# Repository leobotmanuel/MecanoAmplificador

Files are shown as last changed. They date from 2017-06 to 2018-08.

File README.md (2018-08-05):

# Mecano Amplificador  

## Comunicación libre. Jornadas de Bajo Coste.
### Albacete, Julio 2017
Dispositivo programable del proyecto Amplificación Mecanoceptiva de Maite Aliaga.

Presentación de la [Comunicación Libre](https://github.com/leobotmanuel/MecanoAmplificador/blob/master/doc/ALIAGAamplificacionmecanoceptiva.pdf) en las [Jornadas de Bajo Coste](http://www.crmfalbacete.org/recursosbajocoste/default.asp) de Albacete, 6-7-8 de Julio de 2017.

Dispositivo Mecano Amplificador, [dossier concurso](https://github.com/leobotmanuel/MecanoAmplificador/blob/master/doc/ALIAGAdossierconcursoBajoCoste2017AmplificacionMecanoceptiva.pdf).

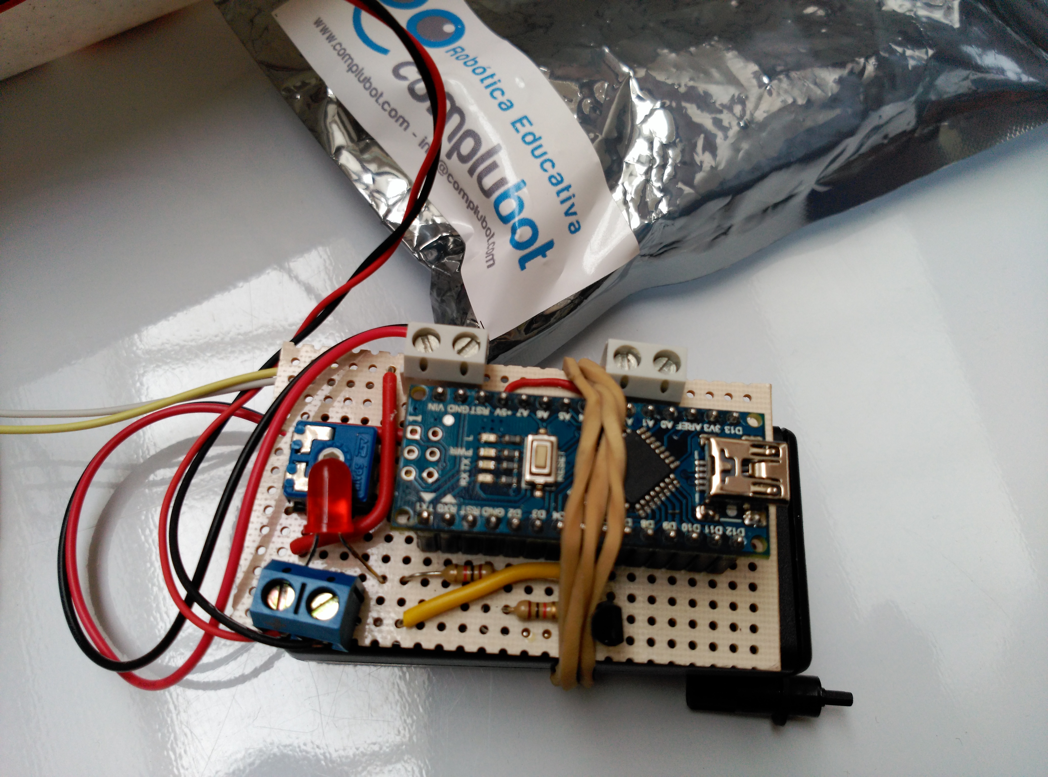
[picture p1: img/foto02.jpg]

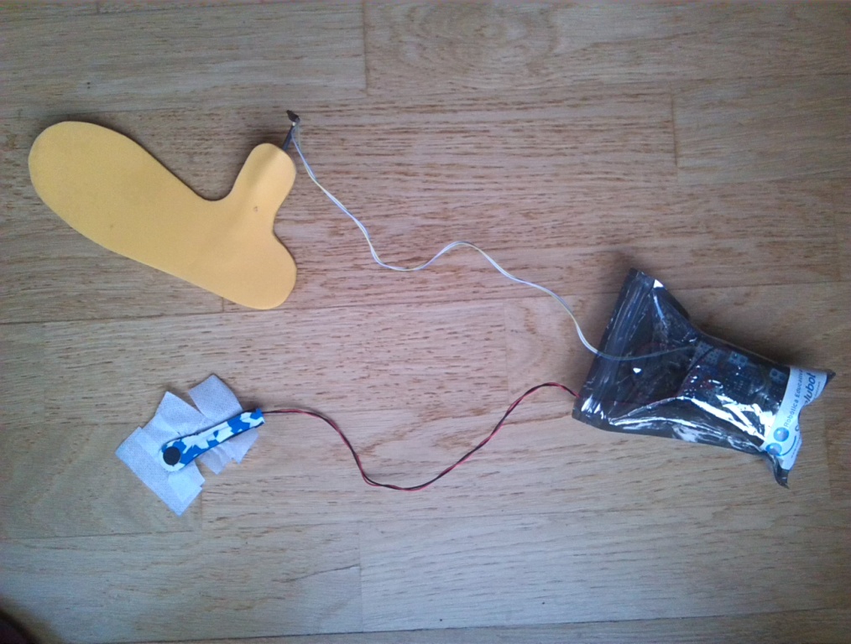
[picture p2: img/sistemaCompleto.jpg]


Colcación del Mecano Amplificador en las personas.

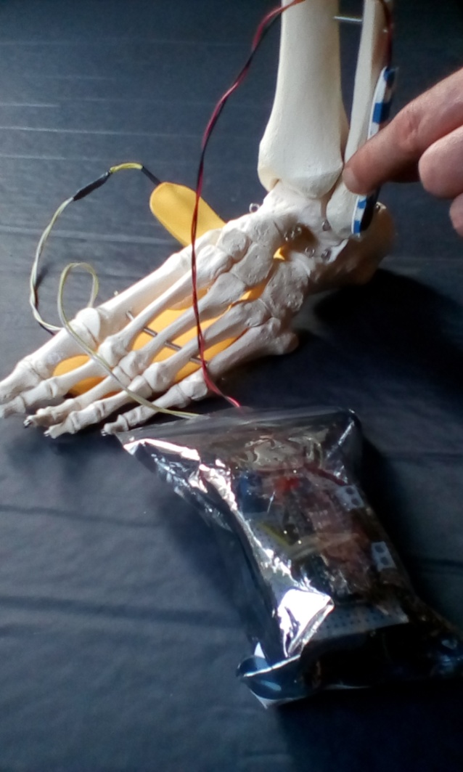
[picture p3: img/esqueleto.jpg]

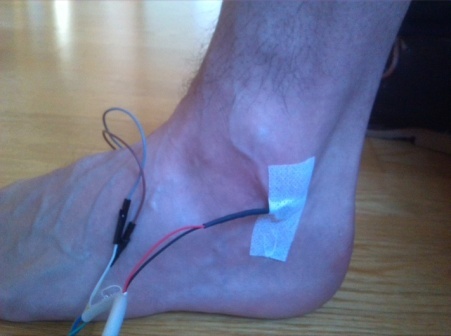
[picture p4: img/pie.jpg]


Programa para el [Nano-Arduino](https://github.com/leobotmanuel/MecanoAmplificador/blob/master/software/mecanoAmplificador.ino)

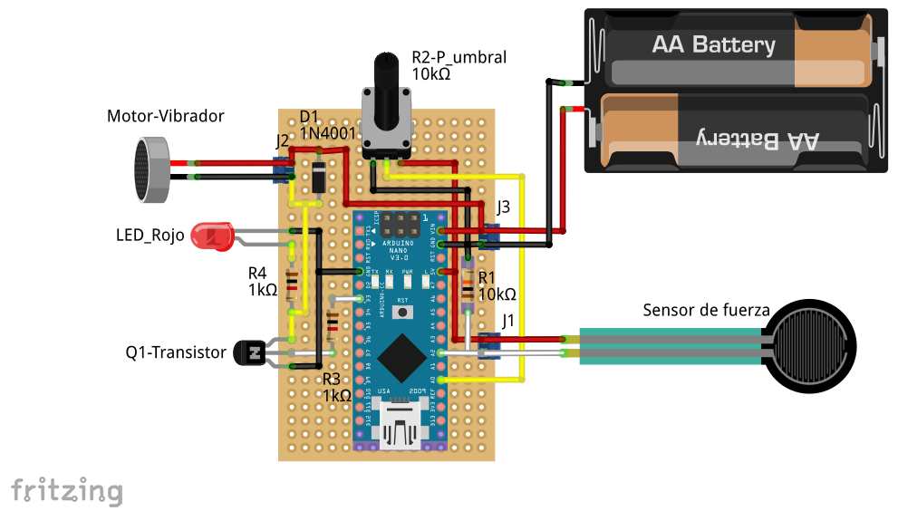
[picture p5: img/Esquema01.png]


[Esquema electrónico](https://github.com/leobotmanuel/MecanoAmplificador/blob/master/doc/Esquema02.fzz)

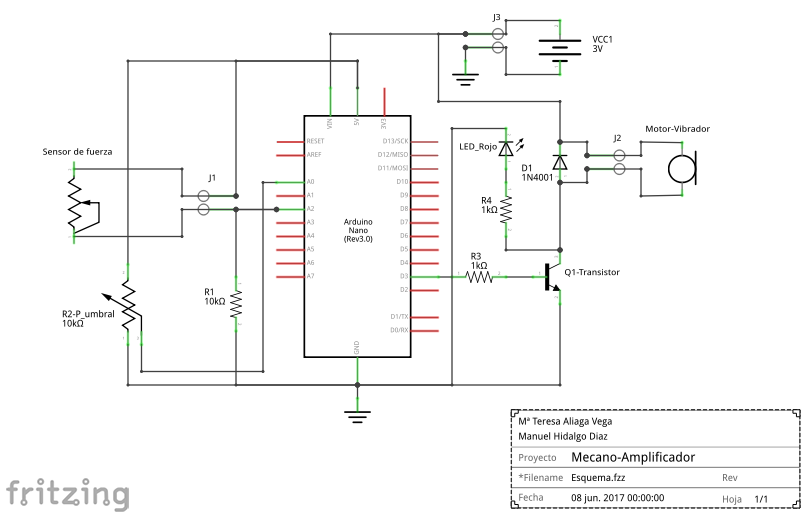
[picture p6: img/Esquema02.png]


[PROPUESTAS DE MEJORA](https://github.com/leobotmanuel/MecanoAmplificador/blob/master/doc/propuesta/README.md)

[Volver índice](https://mecanoceptiva.github.io/)

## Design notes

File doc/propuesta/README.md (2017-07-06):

# Propuestas de mejora


- Reducir el tamaño  del sistema completo.
- Conseguir una autonomia aceptable.
- Colocar de manera cómoda y funcional.

[ARDUINO MINI](https://store.arduino.cc/arduino-mini-05)

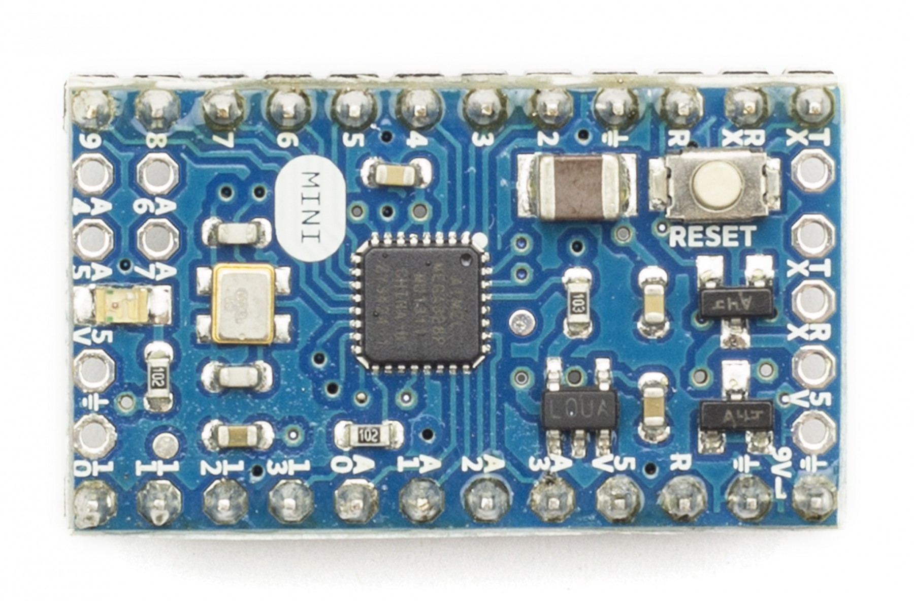
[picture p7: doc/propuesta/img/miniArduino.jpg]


[WEMOS](http://robotpersonal.es/product.php?id_product=223)

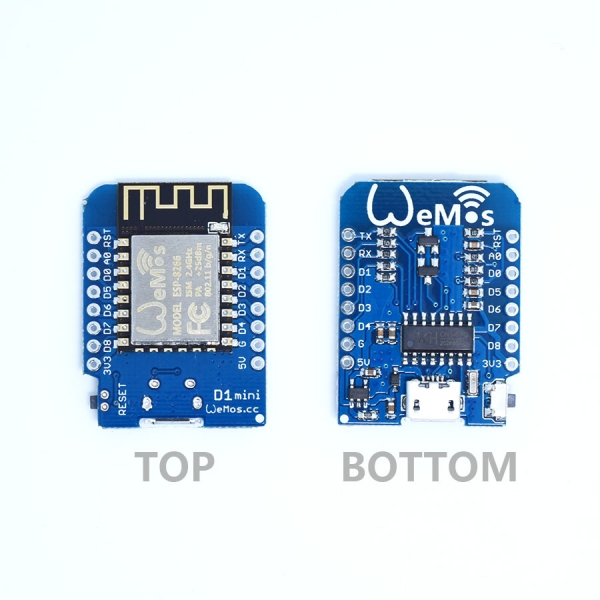
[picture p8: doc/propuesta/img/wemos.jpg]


[Shield](http://robotpersonal.es/category.php?id_category=89) para Wemos

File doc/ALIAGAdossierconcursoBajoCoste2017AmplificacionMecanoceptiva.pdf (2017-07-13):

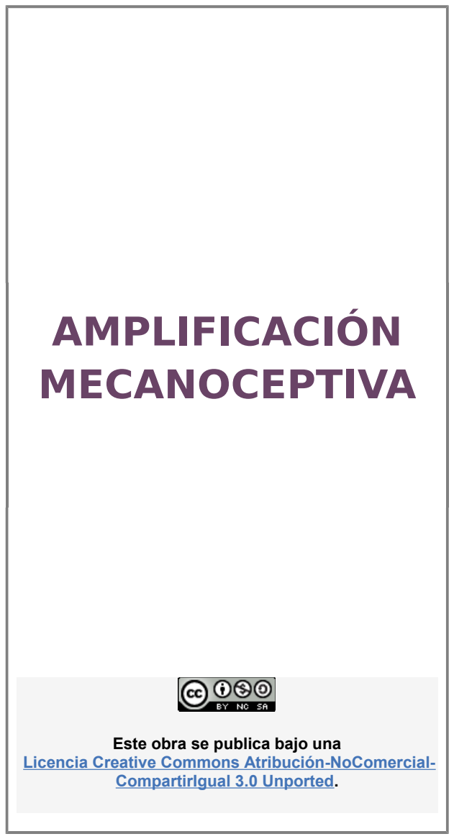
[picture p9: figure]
AMPLIFICACIÓN MECANOCEPTIVA; Este obra se publica bajo una Licencia Creative Commons Atribución-NoComercial- CompartirIgual 3.0 Unported.

# AMPLIFICACIÓN MECANOCEPTIVA

### Breve descripción

Presentamos un prototipo de dispositivo electrónico portátil para proporcionar mecano-estimulación funcional.

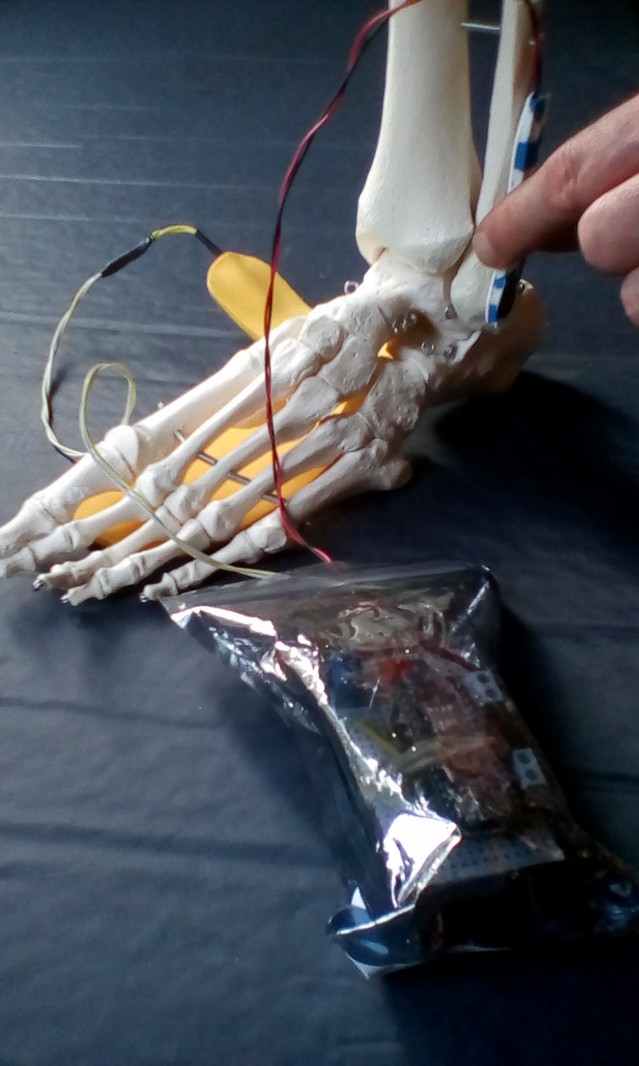
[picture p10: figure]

Este proyecto tecnológico busca potenciar el funcionamiento natural del aparato osteo-articular como órgano sensorial, para que tenga un rol preponderante en la organización de la musculatura durante las diferentes posturas o desplazamientos.

### Para quién se hizo y con qué objeto

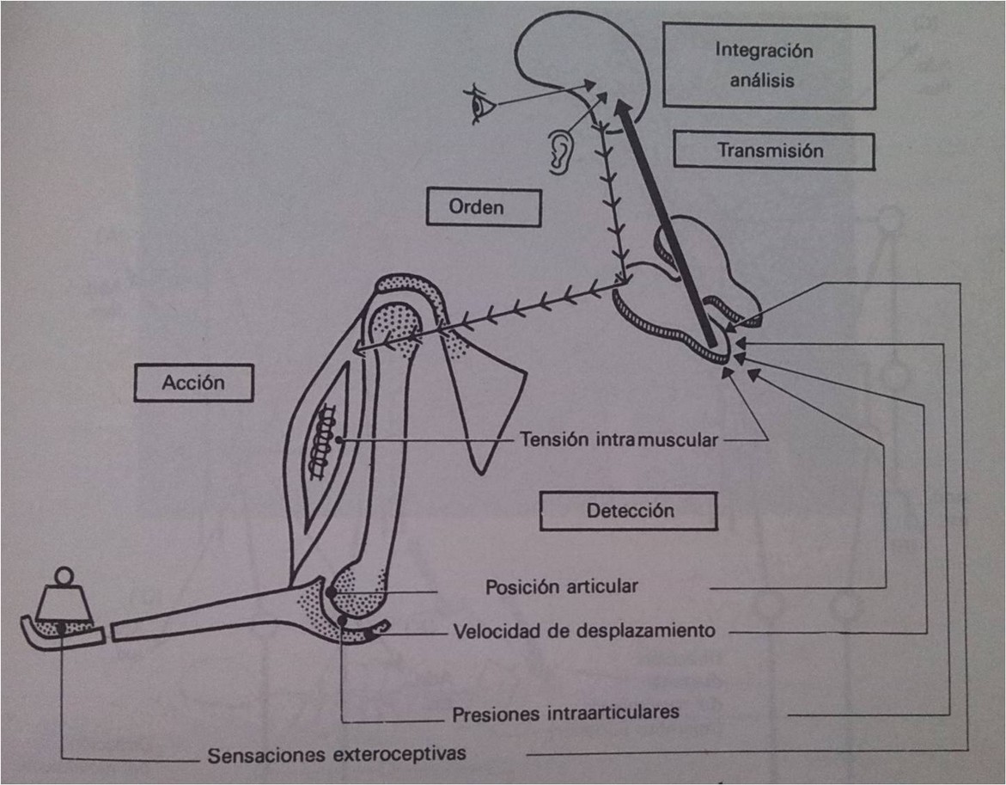
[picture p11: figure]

DISFUNCIONES EN LA PERCEPCIÓN DE LA PROPIA POSTURA CORPORAL Y DE LOS PROPIOS MOVIMIENTOS EN EL ESPACIO

La motricidad se coordina automáticamente desde el sistema nervioso central (encéfalo y médula espinal) gracias a la información procedente de diversos receptores sensoriales: visión, sistema vestibular, tacto y propiocepción (muscular y periarticular).

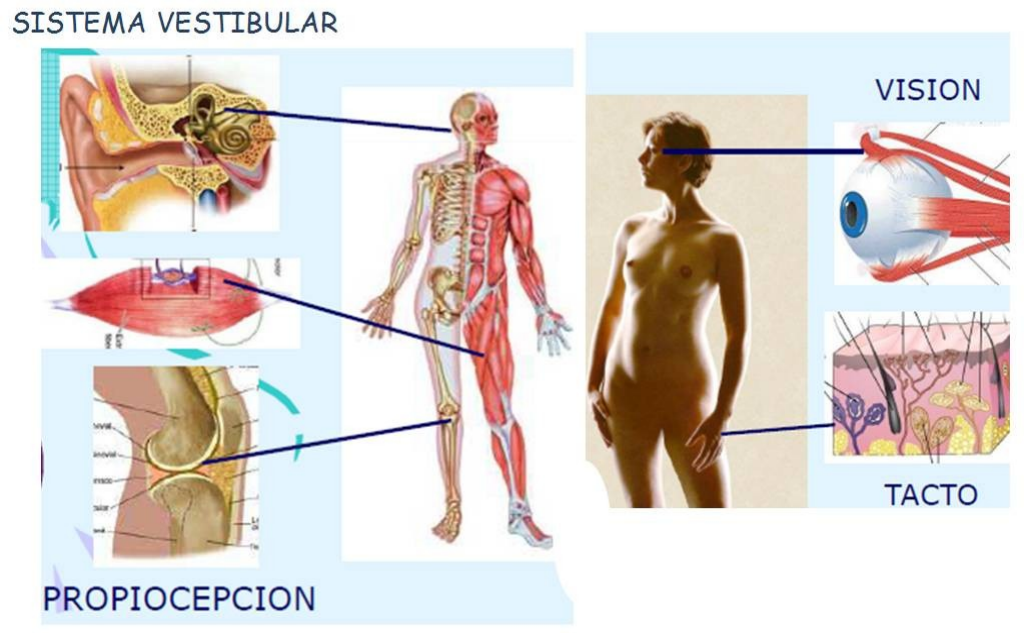
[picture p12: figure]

En caso de una patología que afecte al circuito neurológico de la contracción muscular habrá un
mal | funcionamiento | en | los | "husos
neuromusculares", unos muelles sensores de la longitud y de la velocidad con que se está tensando o relajando cada músculo.

Si su circuito sensorio-motor alternativo no está afectado por la lesión original, otros sensores llamados "mecanoceptores", existentes en los tejidos de alrededor de las articulaciones (tendones y fascias, ligamentos y cápsulas, superficies de contacto entre los huesos) seguirán informando adecuadamente sobre la posición y las presiones en el esqueleto.

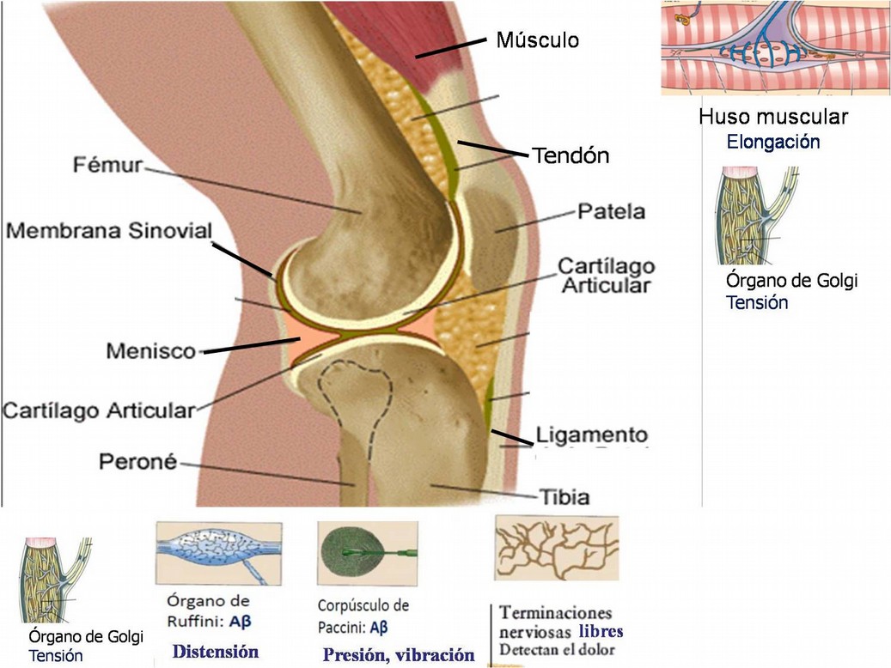
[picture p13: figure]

Vamos a traducir esto a nivel funcional. Por ejemplo durante la marcha, el tobillo y la rodilla deben flexionarse suavemente para amortiguar la pisada. Sin embargo en los niños o adultos con hemiplejia, el músculo tríceps sural de la extremidad inferior afectada suele presentar contracciones excesivas o a destiempo y fallos en el momento de necesitar relajarse ("hipertonia", “espasticidad”).

Esta descoordinación produce una extensión errónea del tobillo y de la rodilla que impide soportar el apoyo del cuerpo sobre el pie, perdiendo mucha estabilidad al dar pasos con la

otra extremidad inferior.

POSIBILIDADES TERAPÉUTICAS
De momento las intervenciones médicas (ortesis para ayudar a posicionar las articulaciones, fármacos paralizantes o cirugía debilitadora sobre los músculos…) solamente han podido contener parcialmente dichas consecuencias biomecánicas adversas de una mala regulación neuromotríz.

Existen por otra parte en Fisioterapia y Psicología técnicas o ejercicios que han demostrado empíricamente una armonización general aunque transitoria de las tensiones musculares, conseguida desde algún tipo de estimulación mecánica realizada sobre el esqueleto.

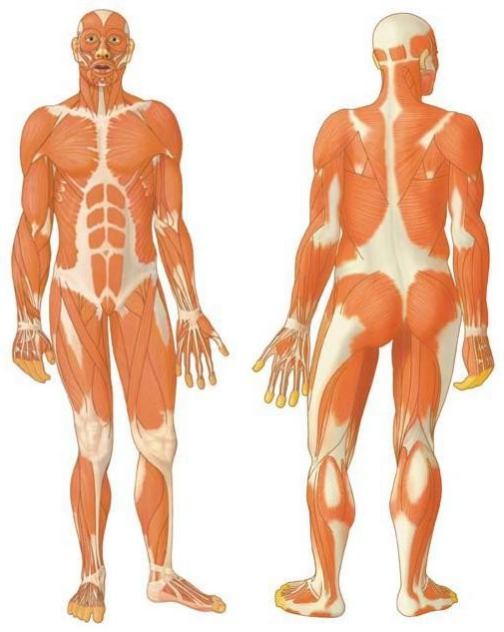
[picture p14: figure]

Observando en conjunto las prominencias óseas más favorables y las direcciones de presión más eficaces encontramos un patrón biomecánico simulando el enderezamiento postural automático contra la gravedad y los impactos recibidos por el cuerpo humano cuando está moviéndose sobre una
superficie | de | desplazamiento | (volteando,
sentándose, gateando, caminando, etc).

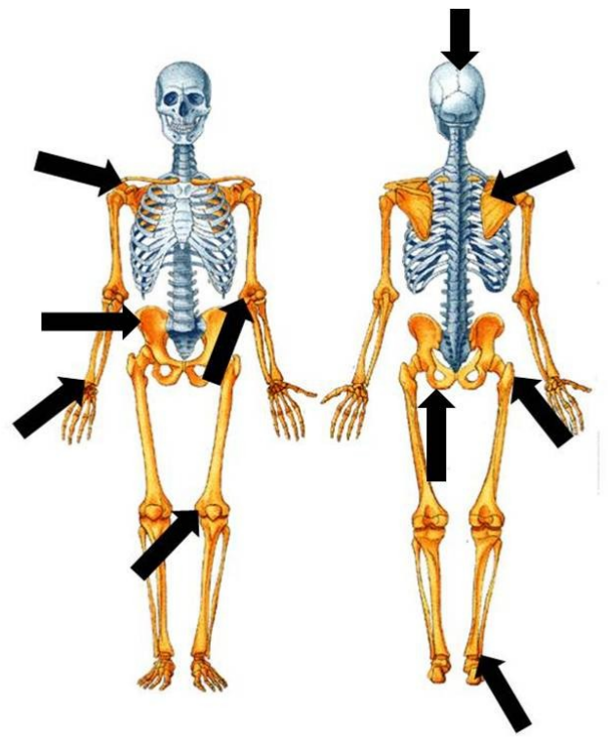
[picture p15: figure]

Nuestra propuesta innovadora, basada en el actual paradigma del control motor múltiple, es realizar una intervención educativa para que el sistema nervioso central pueda aprender a realizar una mejor regulación motora gracias a disponer durante su continua actividad ensayo-error de una información sensorial específicamente modificada. Subiremos el “volumen" del estímulo “peso corporal apoyado” gracias a convertirlo por medios tecnológicos en una vibración más intensa que recorra el hueso en la dirección adecuada y alcance a muchos mecanoceptores. Al conseguir ser “oído" con más calidad creemos que comenzará un
periodo | de | auto-reeducación | del | cual
desconocemos lo que es capaz de generar, pero confiamos en la plasticidad neuronal que reina durante la infancia.
Utilizando un símil auditivo: a diferencia de proporcionarle al sistema nervioso central los estímulos que le faltan por una vía artificial, como hace un implante coclear, aquí solamente pretendemos amplificar una vía natural, como hace un audífono.

### Materiales y modo de funcionamient

o

Hemos realizado un diseño destinado a mejorar la postura de pie y durante la marcha, actuando directamente sobre los huesos e indirectamente sobre la musculatura responsable de la reacción de apoyo automática necesaria para sostener el peso del cuerpo.

Tendremos que materializar e interconectar en la práctica los siguientes conceptos teóricos:

- una fuente de estimulación mecánica artificial suplementaria sobre los mecanoceptores, la cual debe ser adecuada en intensidad, en ubicación y en direccionalidad.
- un elemento capaz de activar y desactivar de dicha estimulación con una lógica sensorial y
biomecánica, | para | que | sea | simultánea | al
funcionamiento natural de los mecanoceptores durante la carga.

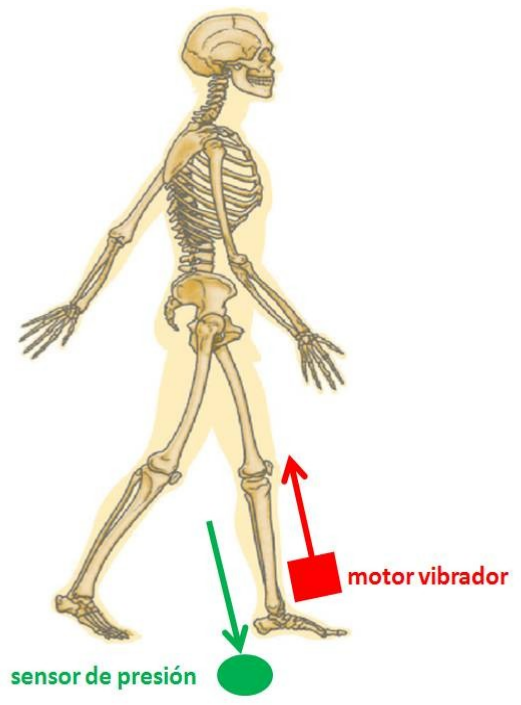
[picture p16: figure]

a) motor vibrador

Un cabezal masajeador que funciona enchufado a la red eléctrica es bien percibido incluso a través de la ropa, calzado y férulas por los niños con deficiencia neuromotríz, quienes son capaces de localizar sin ayuda de la visión en qué parte del cuerpo están recibiendo el contacto del aparato. La potencia real de su motor vibrador es alrededor de 10 watios.

Para aligerar el dispositivo hemos probado con otros motores vibradores de menor potencia hasta elegir un componente de telefonía móvil, el cual también llega a percibirse claramente si lo colocamos exento de carcasa sobre la piel de las prominencias óseas. Su potencia en funcionamiento continuo es de 0’225 watios (3 Voltios x 75 miliAmperios).

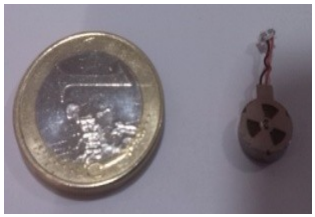
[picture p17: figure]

Sobre su colocación, descartamos ubicarlo debajo del calcáneo porque podría bloquearse al recibir encima todo el peso corporal y preferimos acoplarlo en el extremo distal del peroné porque dicho hueso tiene la direccionalidad adecuada, paralelo a la tibia y consecutivo al fémur, y además es una prominencia muy reconocible y accesible.

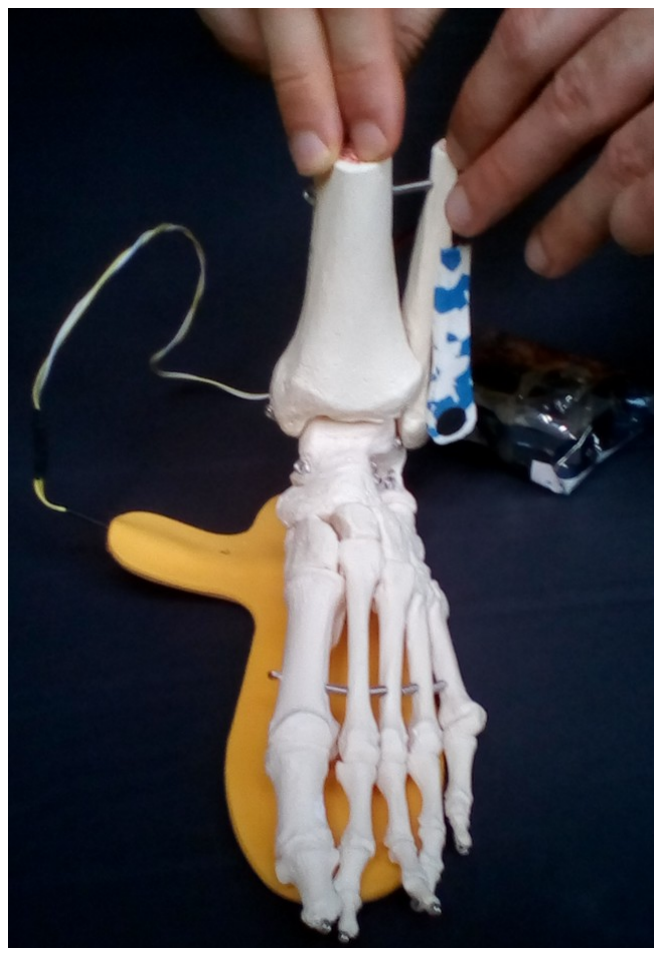
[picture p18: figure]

Se fija mediante papel adhesivo de enfermería (elástico, transpirable, antialérgico).

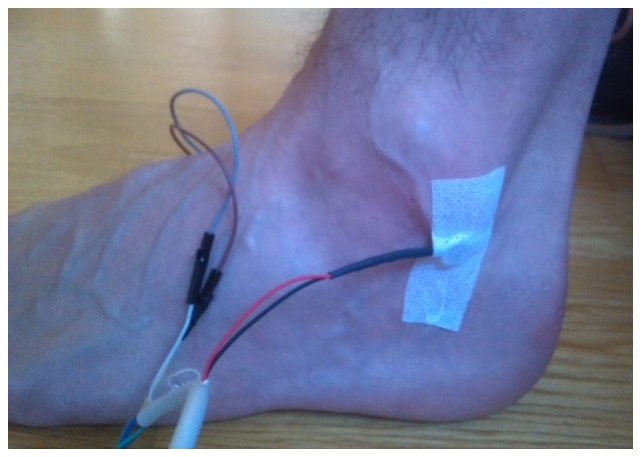
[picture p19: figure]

b) sensor de presión

Componente electrónico muy pequeño y delgado que reacciona, cambiando su resistencia eléctrica, al recibir una carga sobre su estructura. Integrado dentro de una plantilla fabricada en 2 capas con la ayuda del técnico ortopeda: arriba Goma Eva de 3 mm y debajo Cuerolite de 2 mm . El posible usuario típico tiene un peso corporal alrededor de 30 kg y usa una talla 30 de calzado.

c) placa electrónica programable (Arduino-Nano)

Se requiere para hacer funcionar el motor vibrador
de | forma | pulsante | (reduce | consumo | y
calentamiento de los componentes) y para ponerlo a las órdenes del sensor de presión.

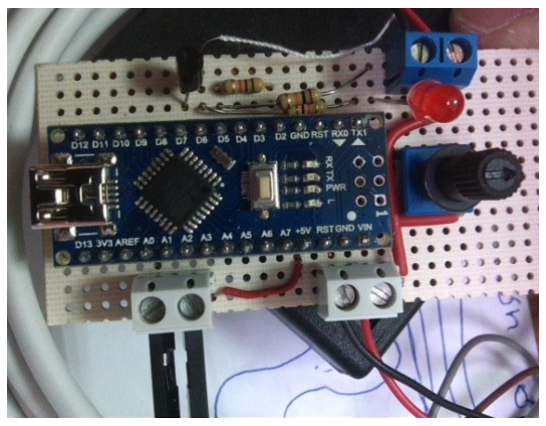
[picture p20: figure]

Tras varias pruebas de confort decidimos que cada pulso dure 0’5 seg y la pausa intermedia dure otros 0’5 seg, resultando una frecuencia conjunta del ciclo de 1 Hz.

d) Fuente de energía

Alimentamos su funcionamiento mediante un porta-pilas para 2 pilas de 1,5 V que incluye un interruptor manual. Con un tiempo de aplicación estandarizado en 20 min y al ser pulsante las pilas durarán bastante más de 6 h antes de requerir ser cambiadas.

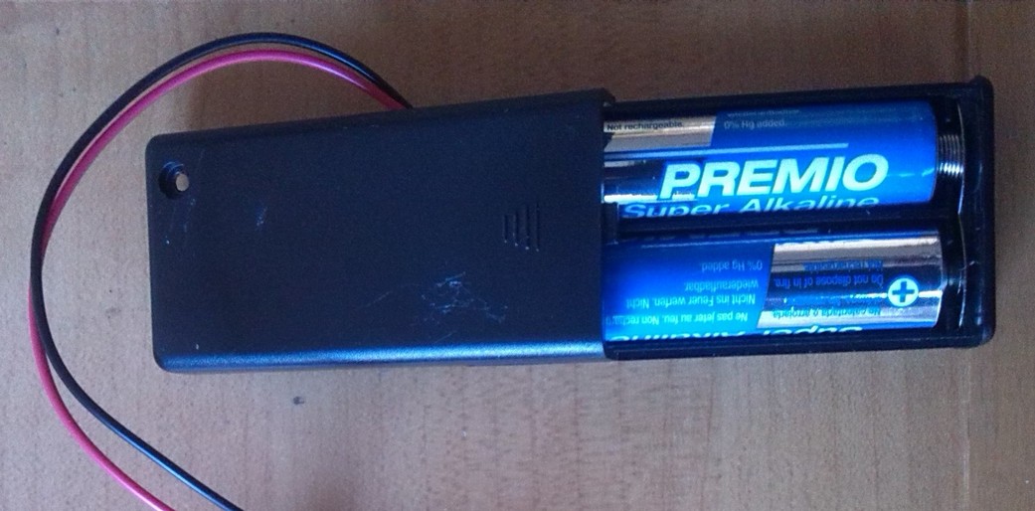
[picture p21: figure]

e) elementos de acoplamiento, protección y transporte
Metemos placa electrónica y porta-pilas dentro de un envoltorio plástico anti-estática. Reducimos al mínimo posible la longitud del cableado sin que se produzcan tirones.

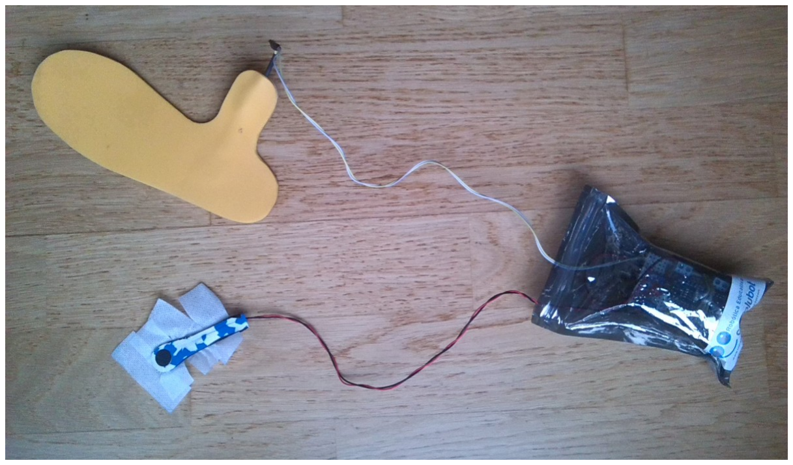
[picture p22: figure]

Sujeción en la parte delantera de la pierna y por encima del tobillo para no entorpecer su
movimiento, | mediante | materiales | textiles:
calcetines de algodón, venda tubular, venda compresiva...

### Proceso de elaboración

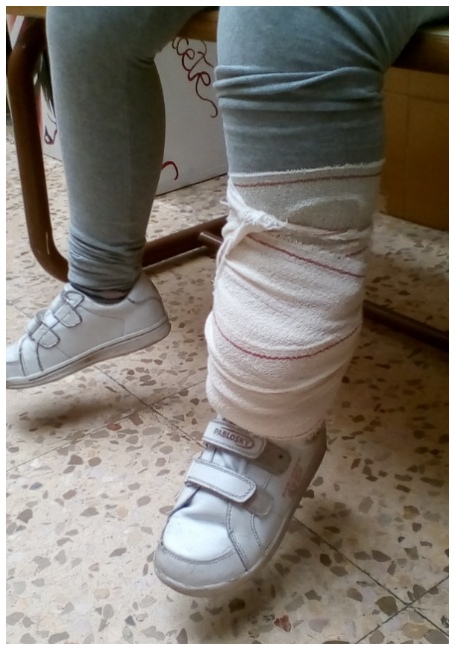
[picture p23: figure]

Imprescindible | trabajo | colaborativo | entre
Fisioterapeuta, Ingeniero y Técnico Ortopeda.

Precauciones - Los cables del sensor de presión y del motor vibratorio pueden romperse debido al roce o al
plegado | causados | durante | los | movimientos
repetidos del pie dentro del calzado. Hay que
protegerlos | forrándolos | con | tubo | plástico
termorretráctil y prolongando la plantilla en forma de ala interna.

- Si el motor no está colocado exactamente sobre el hueso elegido la vibración se perderá en los tejidos blandos cercanos (piel, grasa, músculos) sin poder ser transmitida a distancia a través del esqueleto, hasta los mecanoceptores de la rodilla y de la cadera

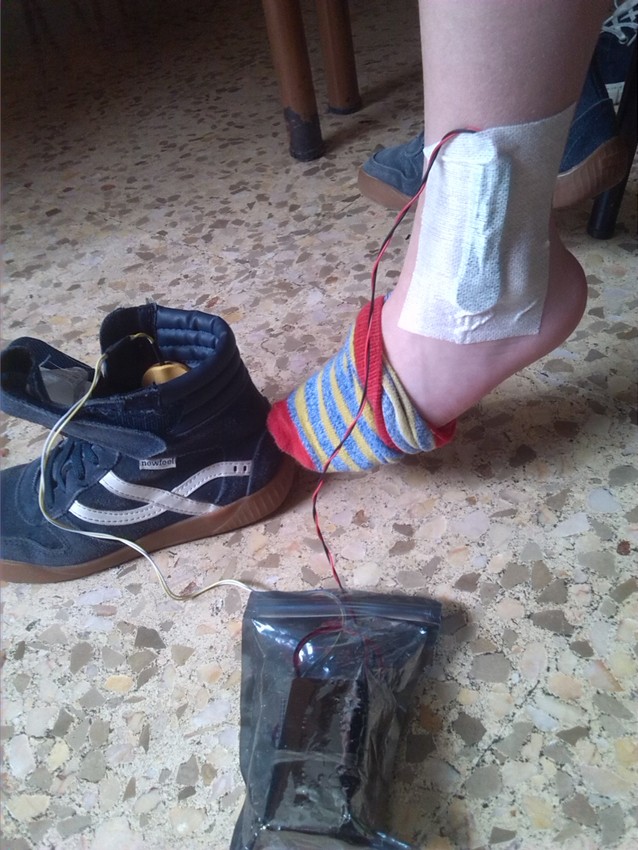
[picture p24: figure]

- La dosis temporal ideal no debe prolongarse más
de | 30 | min, | puesto | que | comenzaría | un
acostumbramiento y una ignorancia sensorial, o en el peor de los casos una saturación sensorial con signos de malestar vegetativo. Tampoco hay que acortar demasiado el tiempo de aplicación para asegurarnos de que se llegan a producir efectos, como mínimo15 min.
- Es necesario un periodo de investigación clínica en los ámbitos de la Educación y la Rehabilitación antes de poder probar las observaciones realizadas: mayor conciencia corporal, mayor libertad articular, distribución más simétrica del peso corporal sobre ambas extremidades inferiores, aumento en la velocidad de la marcha, etc.

### Autores y datos de contacto

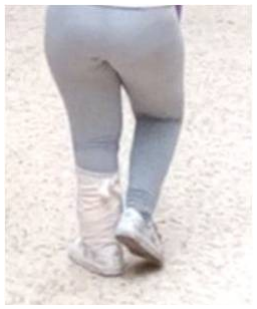
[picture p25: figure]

Apellidos: ALIAGA VEGA
Nombre: MAITE
Correo electrónico : <aliagamaite@gmail.com>

Apellidos: HIDALGO DÍAZ
Nombre: MANUEL

MECANO-AMPLIFICADOR: ESQUEMA DE LOS COMPONENTES

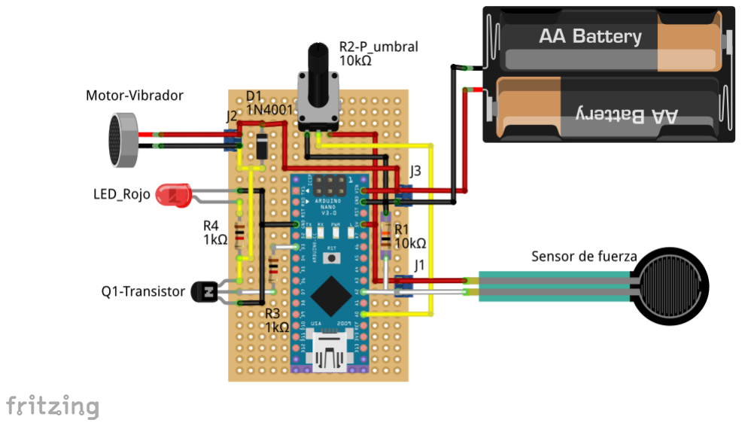
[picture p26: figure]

Los componentes del Mecano-Amplificador son:

- Potenciómetro (R2-P_umbral).- es una resistencia variable y permite ajustar el valor umbral cuando la persona está en reposo y el dispositivo no tiene que actuar.
- LED_Rojo.- dispositivo luminoso que se enciende cuando actúa el motor-vibrador. Permite ajustar el umbral del dispositivo.
- Motor-Vibrador.- motor eléctrico que produce las vibraciones en el punto donde se va a hacer la amplificación mecanoceptiva. Se activa cuando el valor del sensor de fuerza o presión sobrepasa el valor umbral que se ha ajustado con el potenciómetro, .
- Microcontrolador Atmel328p.- dispositivo electrónico programable (su denominación comercial Arduino-Nano) que controla el Mecano-Amplificador. Tiene grabado el programa que lee los valores del sensor de fuerza, si sobrepasa el umbral, activa el motor-vibrador a intervalos de 0,5s al mismo tiempo que enciende el LED_Rojo. En caso contrario lo desactiva.

El resto de componentes electrónicos y conectores son necesarios para el correcto funcionamiento de los circuitos.

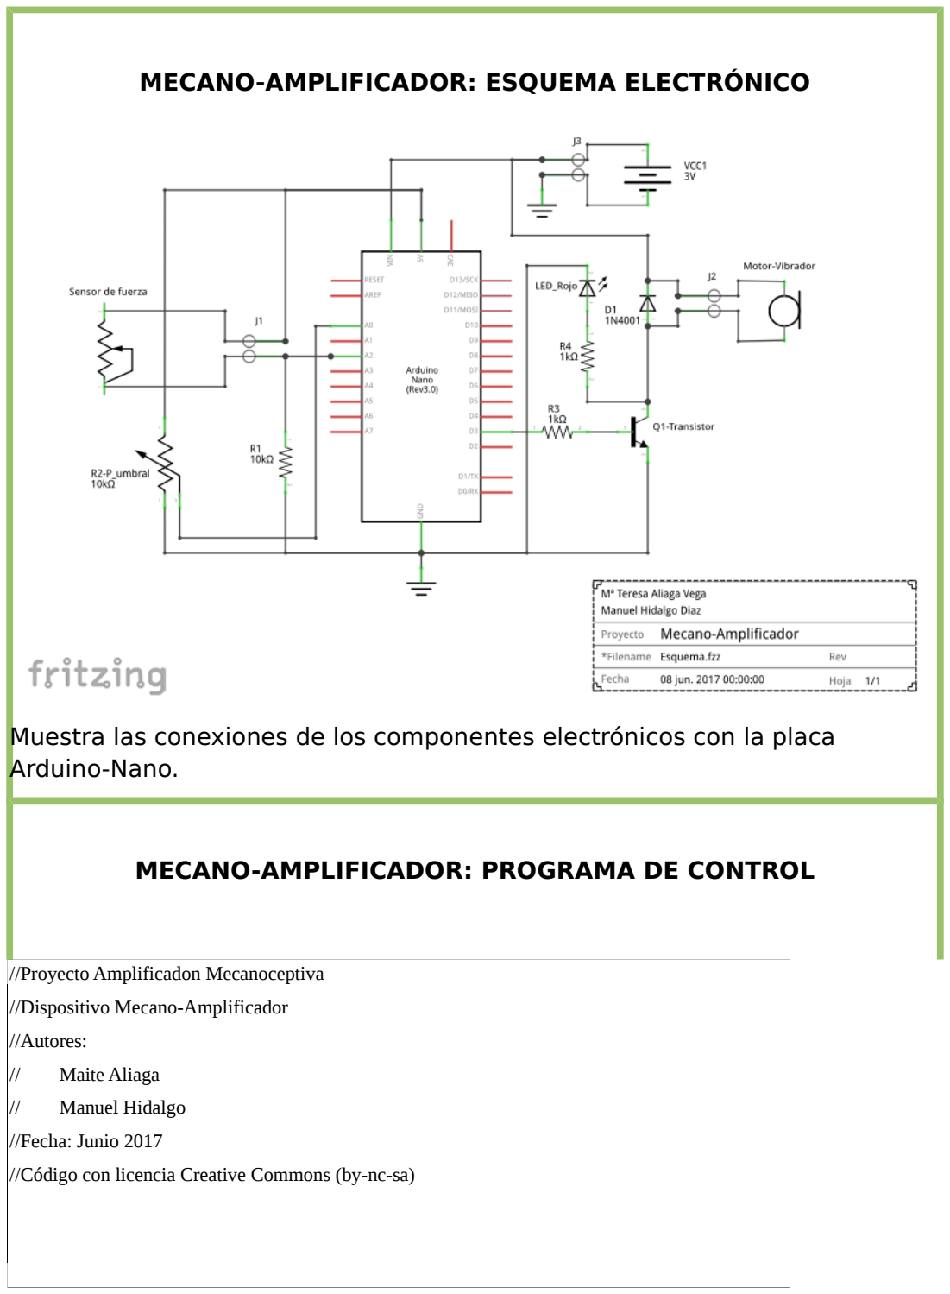
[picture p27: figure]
MECANO-AMPLIFICADOR: ESQUEMA ELECTRÓNICO; Arduino-Nano.; MECANO-AMPLIFICADOR: PROGRAMA DE CONTROL; //Proyecto Amplificadon Mecanoceptiva; //Dispositivo Mecano-Amplificador; //Autores:; Maite Aliaga; Manuel Hidalgo; //Fecha: Junio 2017

Muestra las conexiones de los componentes electrónicos con la placa

//Código con licencia Creative Commons (by-nc-sa)

//declaracion de variables y pines
int sensorPinA2 = A2; // Sensor conectado a Analog 2
int motorPinD3 = 3; // LED conectado a Pin 3 (PWM)
int resRead; | // La Lectura de la Resistencia por División de Tensión
int umbral; | // Umbral de activacion
int potPinA0 = A0; | // Marca el umbral conectado a Analog 0

//programa
void setup()
{
Serial.begin(9600); // Enviaremos la información de depuración a través del Monitor de Serial pinMode(motorPinD3, OUTPUT);
}
//programa principal
void loop()
{
resRead = analogRead(sensorPinA2); // lectura del sensor (A2) //escribe el valor de la lectura del sensor de fuerza Serial.print("Lectura sensor de fuerza = ");
Serial.print(resRead);

umbral = analogRead(potPinA0); // umbral (A0) es igual a la lectura del sensor (A2) //escribe el valor de la lectura del umbral
Serial.print("\tLectura del umbral = ");
Serial.println(umbral);

//activa el motor-vibrador si cumple la condicion if (resRead > umbral) {
digitalWrite(motorPinD3, 1);
delay(500);
}

//desactiva el motor-vibrador digitalWrite(motorPinD3, 0); delay(500);
}

Programa de control que se graba en la placa Arduino-Nano con el entorno de programación (IDE) de Arduino.
La lógica del programa de control se puede entender a través de los comentarios, líneas de código que empiezan con //.
El programa empieza con la función loop() leyendo el valor del sensor de fuerza y guardar el valor en la variable resRead. También lee el valor del potenciómetro que lo guarda en la variable umbral, que sirve de referencia para activar el motor-vibrador durante 500 ms que se ejecuta con el código de la estructura de control condicional:
if (resRead > umbral) {
digitalWrite(motorPinD3, 1);
delay(500);
}
Si esta condición no se cumple el motor permanece siempre inactivo. digitalWrite(motorPinD3, 0);
delay(500);
Las líneas de código que empiezan con Serial.print(), se usan para visualizar el valor del sensor de fuerza y el umbral por el monitor que tiene el IDE de programación en el PC cuando la placa Arduino-Nano está conectado con el cable USB.

SENSOR DE FUERZA O PRESIÓN: CARACTERÍSTICAS (1)

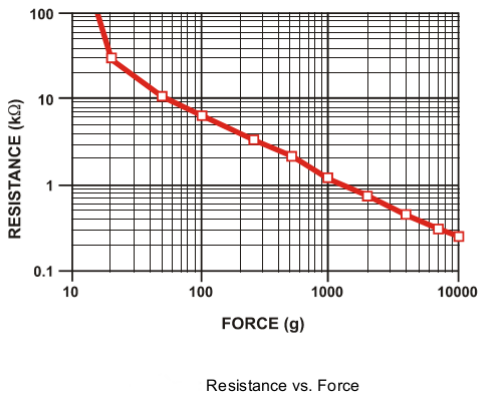
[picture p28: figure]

Esta gráfica muestra el comportamiento del sensor de fuerza o presión. Si el sensor no recibe una presión la resistencia tiene un valor muy elevado y si se presiona sobre el sensor la resistencia se reduce. En la siguiente gráfica se ve como varia la tensión al variar la fuerza aplicada al sensor.

SENSOR DE FUERZA O PRESIÓN: CARACTERÍSTICAS (2)

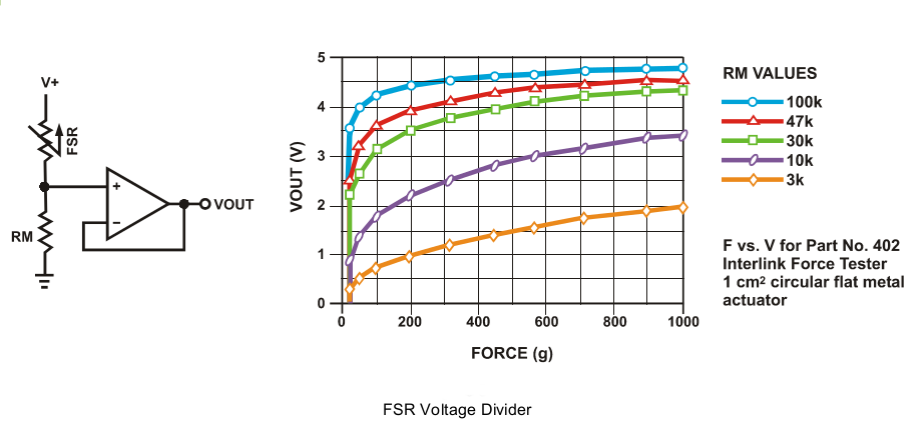
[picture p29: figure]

En la imagen de la izquierda se ve un circuito, divisor de tensión, que se utiliza en el Mecano-Amplificador para la lectura de sensor de fuerza (FSR) junto con una resistencia (RM). En función de la resistencia (RM) que se ponga en el divisor de tensión la variación de tensión es diferente dando las curvas que se muestran en la gráfica de la derecha. Se ha elegido la curva correspondiente a 10k porque da un margen de tensión mayor en la lectura de la fuerza aplicada al sensor permitiendo una mejor precisión en la lectura por el microcontrolador.

SENSOR DE FUERZA O PRESIÓN: CARACTERÍSTICAS (3)

Detalles de las dimensiones del sensor de fuerza o presión.

MOTOR VIBRADOR: CARACTERÍSTICAS

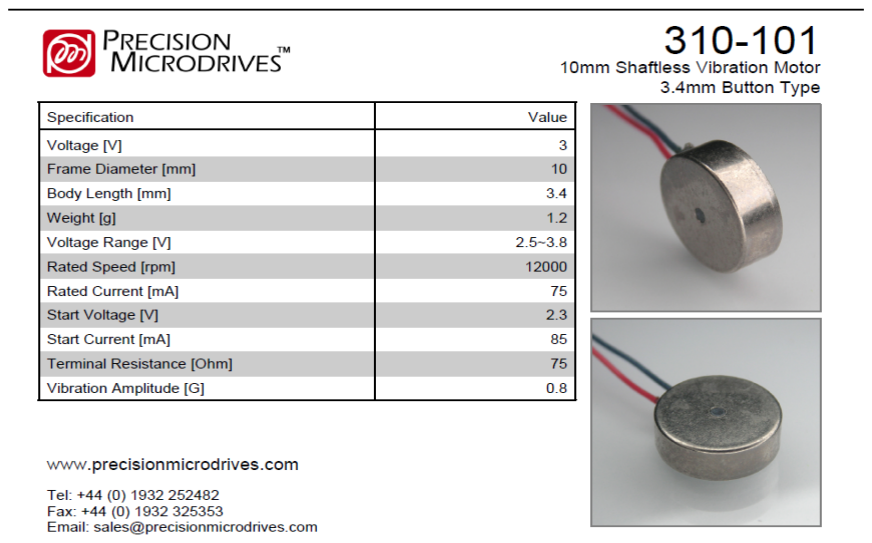
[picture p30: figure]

Tabla con las características mecánicas y eléctricas del motor-vibrador. Destacando su tensión nominal de 3v y consumo de 75mA.

MOTOR VIBRADOR: ESQUEMA


Detalles de las dimensiones del motor-vibrador.

REPOSITORIO DEL MECANO-AMPLIFICADOR


Repositorio de documentación del Mecano-Amplicador. https://github.com/leobotmanuel/MecanoAmplificador

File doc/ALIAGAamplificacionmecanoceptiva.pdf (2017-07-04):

AMPLIFICACIÓN MECANOCEPTIVA; Un dispositivo electrónico funcional, portátil y bajocoste para la fisioterapia educativa o rehabilitadora; Maite Aliaga (Fisioterapeuta) Manuel Hidalgo (Ingeniero)

AMPLIFICACIÓN MECANOCEPTIVA

# Percepción de la propia postura corporal

y de los propios movimientos en el espacio.

Disfunciones sensoriomotrices

# Disfunciones sensoriomotrices: ejemplo de alteración de la marcha

# AMPLIFICACIÓN MECANOCEPTIVA


# Disfunciones sensoriomotrices:

algunas posibilidades terapéuticas.


Concepto de Amplificación Mecanoceptiva.

“potenciar el funcionamiento natural del aparato osteoarticular como órgano sensorial, para que tenga un rol preponderante en la organización de la musculatura durante las diferentes posturas o desplazamientos”

# Un dispositivo Mecanoamplificador:

diseño, materiales, elaboración y funcionamiento.

//Proyecto Amplificadon Mecanoceptiva //Dispositivo Mecano-Amplificador //Autores:
// | Maite Aliaga
// | Manuel Hidalgo
//Fecha: Junio 2017
//Código con licencia Creative Commons (by-nc-sa) //declaracion de variables y pines
int sensorPinA2 = A2; // Sensor conectado a Analog 2
int motorPinD3 = 3; | // LED conectado a Pin 3 (PWM)
int resRead; | // La Lectura de la Resistencia por División de Tensión
int umbral; | // Umbral de activacion
int potPinA0 = A0; | // Marca el umbral conectado a Analog 0
//programa
void setup()
{
Serial.begin(9600); // Enviaremos la información de depuración a través del Monitor de Serial pinMode(motorPinD3, OUTPUT);
}
//programa principal
void loop()
{
resRead = analogRead(sensorPinA2); // lectura del sensor (A2) //escribe el valor de la lectura del sensor de fuerza
Serial.print("Lectura sensor de fuerza = ");
Serial.print(resRead);
umbral = analogRead(potPinA0); // umbral (A0) es igual a la lectura del sensor (A2) //escribe el valor de la lectura del umbral
Serial.print("\tLectura del umbral = ");
Serial.println(umbral);
//activa el motor-vibrador si cumple la condicion if (resRead > umbral) {
digitalWrite(motorPinD3, 1);
delay(500);
}
//desactiva el motor-vibrador digitalWrite(motorPinD3, 0); delay(500);
}

# Un dispositivo Mecanoamplificador: diseño, materiales, elaboración y

funcionamiento.


Un dispositivo Mecanoamplificador:
diseño, materiales, elaboración y funcionamiento.

# Lesión medular


# Un dispositivo Mecanoamplificador:

diseño, materiales, elaboración y funcionamiento.

# Parálisis cerebral infantil

# Parkinson

# observaciones realizadas: §mayor conciencia


corporal
§mayor libertad articular
§apoyos más simétrico
sobre ambas
extremidades inferiores
§aumento en la velocidad
de la marcha, etc

recogida de datos objetivos y pruebas estadísticas

Investigación clínica en Educación y Rehabilitación.

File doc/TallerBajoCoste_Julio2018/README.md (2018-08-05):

# Amplificación Mecanoceptiva  

## Taller de Amplificación Mecanoceptiva. Jornadas de Bajo Coste.
### Albacete, Julio 2018
Taller práctico del proyecto Amplificación Mecanoceptiva de Maite Aliaga.

Presentación de las novedades del proyecto en las [Jornadas de Bajo Coste](http://www.crmfalbacete.org/recursosbajocoste/default.asp) de Albacete, 12-13-14 de Julio de 2018.

El documento de la [presentación](doc/ALIAGATallerAmplifMecanocepBajoCoste2018.pdf).

[Conclusiones](doc/RESUMENPARTICIPANTESAmplificaci%C3%B3nMecanoceptivaBAJOCOSTE2018.pdf) del taller.



[Volver índice](https://mecanoceptiva.github.io/)

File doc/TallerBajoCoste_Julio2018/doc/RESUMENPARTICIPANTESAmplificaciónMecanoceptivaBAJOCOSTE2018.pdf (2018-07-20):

Amplificación Mecanoceptiva BAJOCOSTE 2018

NOMBRE
OCUPACIÓN

23 personas de los ámbitos educativo, socio-sanitario y tecnológico
En cada taller 2 Fisioterapeutas distintos escogidos de entre ellos han colaborado con los 3 responsables

COMENTAR
IOS

Parece que la teoría y las prácticas del taller os han gustado, ójala tengamos la oportunidad de profundizar en otra ocasión.

En cuanto a nuestro objetivo paralelo de ensayar sobre vosotros algunas herramientas para detectar cambios en la estabilidad postural tras una estimulación mecanoceptiva, os damos las gracias porque han pasado muchas cosas interesantes.

PRÁCTICA
DE
ESTIMULAC
IÓN:

MECANO-AMPLIFICA
DOR

A 6 personas les pusimos un MecanoAmplificador en el pié izquierdo y caminaron libremente durante 10-15 min.

Vuestros comentarios:
Mayor conciencia de la pisada.
La sensación de vibración aumenta en el momento de la carga.
Quizá la intensidad es insuficiente para adultos.
Económico y con alto nivel de aceptación por el paciente porque es fácil de poner, discreto, no es incómodo ni doloroso.
No interrumpe ni limita otras actividades con lo que se puede integrar en la vida diaria.

Nuestros comentarios:
Durante la colocación a adultos los cables tiraban, quizá serían mejor de tipo espirales

13 personas aplicaron la Eutonía sobre su hemicuerpo izquierdo, tumbados en el suelo durante 10-20 min.

Vuestros comentarios:
La presión sobre los rebordes óseos se transmite hacia arriba sobre todo desde el tórax, mientras que con el bambú adquiero mayor propiocepción de la musculatura y los tejidos,

PRÁCTICA
DE
ESTIMULAC
IÓN:

EUTONÍA

así como de los rebordes óseos. Después he notado más estabilidad.
Alivio de las partes que tienen más dolor en mi cuerpo.
Calor en el lado izquierdo al entrar en reposo.
Durante los toques no era consciente de ningún cambio pero al terminar he sentido que andaba mucho más enderezada y que tenía la pierna izquierda más larga.
Notaba la pierna izquierda más ligera.
Sensación al ponerme de pié de que la parte izquierda del cuerpo (especialmente la cadera) necesitaba moverse hacia arriba. Mayor sensación de apoyo. Cosquilleo en lado izquierdo. Sentí más equilibrio.
Mayor consistencia corporal, más presencia aquí y ahora.
Los puntos de presión crean una relajación (ligereza) que elimina la tensión.
Relax en la parte izquierda, como si a la parte derecha le faltara algo. Poder normalizar pie, tobillo, rodilla…Sensación agradable de corriente sensitiva, como si notara el cableado de conexiones nerviosas.
Me he relajado mucho y ha mejorado mi propiocepción.
Sensación de mayor pesadez y de apoyo en la parte izquierda.

TEST
INICIALES
Y FINALES:

CRONÓMET
RO

6 personas realizaron cronometraje de una combinación entre el protocolo “Levántate y anda” y el protocolo “10 m de marcha”, con una silla colocada a cada extremo del pasillo.

Entre medias 4 de ellos practicaron Eutonía y los otros 2 se pusieron un MecanoAmplificador.

MecanoA
mp
| ANTES | 20’49/19’60=
| 20’04 seg
| DESPUES | 22’51/24’34=
| 23’42 seg
3’38 | seg
mas
MecanoA mp | ANTES
| 20’42 seg
| DESPUES
| 19’97 seg

igual

Eutonía | ANTES | 24’40/24’78=

24’59 seg
DESPUES | 21’88/20’39=
21’13 seg

3’46 seg
menos

Eutonía ANTES
23’80 seg
DESPUES
22’00 seg

1’80 seg
menos

Eutonía ANTES
26’80 seg
DESPUES
23’35 seg

3’45 seg
menos

Eutonía ANTES
22’70 seg
DESPUES
20’00 seg

2’70 seg
menos

Nuestros comentarios:

En nuestro estudio clínico con 3 niños la velocidad del tapiz rodante era fija y lo que se detectó fue una influencia del MecanoAmplificador sobre su alineación esquelética. Como debido a sus dificultades sensoriomotrices ellos no suelen caminar de una forma eficaz ni estable pensamos que si hubieran podido ir a su velocidad libre ésta tanto podría haber aumentado como disminuido. Por otra parte en cualquier persona sana o con dificultades puede haber un efecto de cansancio tras 15 min caminando con el MecanoAmplificador. Ambas dudas a ser investigadas…

La Eutonía sí que acaba de insinuar aquí una tendencia a aligerar los pasos, cosa que invita a realizar una investigación con más personas para descartar el efecto de haber permanecido tumbados.

Tampoco deben saber que hay un cronómetro, solamente que se les graba un video donde observar cambios posturales.

Y por cierto si alguno de vosotros nos queréis enviar dichos videos os lo agradeceríamos mucho.

TEST
INICIALES
Y FINALES:

WBB+
ORDENADO
R

4 personas se subieron a la WiiBalanceBoard cuyos datos eran capturados (30 seg) desde el ordenador portátil.

Entre medias 2 de ellos practicaron Eutonía y los otros 2 se pusieron un MecanoAmplificador.

Vuestros comentarios:
El desequilibrio aumenta con los pies juntos y sobre una superficie inestable.

Nuestros comentarios:

Hemos reunido las imágenes de la persona (viernes, MecanoAmplificador) donde se aprecia mejor que, según habíamos buscado al diseñar la prueba, la dificultad de mantenerse quieto aumenta progresivamente. Por tanto la herramienta tecnológica saca datos coherentes.

Respecto a los cambios después de la estimulación (imágenes de la fila de abajo), se necesitan más personas y más tratamiento matemático de sus datos para poder realizar afirmaciones honestas. A seguir…

juegos WiiFit.; Entre medias los 3 practicaron Eutonía

3 personas se subieron a la WiiBalanceBoard con pantalla de televisión y consola de

TEST INICIALES Y FINALES:; WBB+ JUEGOS; UBICACIÓN CENTRO GRAVEDAD EQUILIBRIO PATA COJA; ANTES pie izquierdo 59’1%/pie derecho 40’9% DESPUES pie izquierdo 51’1%/pie derecho 48’9%; ANTES 68% DESPUES 75%; ANTES pie izquierdo 48’4%/pie derecho 51’6% DESPUES pie izquierdo 42’4%/pie derecho 57’6%; ANTES 81% DESPUES 85%; ANTES pie izquierdo 49’9%/pie derecho 50’1% DESPUES; ANTES; DESPUES; Nuestros comentarios:; terminar la toma de datos.

No se deben sacar conclusiones generales a partir de las únicas 2 personas que pudieron

La primera persona empezó con asimetría (apoyo mayor sobre su pie derecho) y acabó simétrica. Seguramente se podían apreciar cambios posturales añadidos a nivel del tronco y la cabeza. ¿Y que habría pasado si después hubiese seguido estimulando el lado que faltaba?

La segunda persona empezó simétrica y acabó con asimetría (apoyo mayor sobre su pie derecho que era donde había realizado por error la estimulación, suponemos que de haberse estimulado el lado izquierdo como el resto del grupo habría acabado con asimetría de apoyo mayor sobre su pie izquierdo). Después de medir variaciones deberíamos haber seguido estimulando el otro hemicuerpo para igualar.

TEST
INICIALES
Y FINALES:

GONIÓMET
RO

Se realizaron goniometrías de la pierna izquierda a 4 personas, tendidos boca arriba en una camilla.

Entre medias 2 de ellos practicaron Eutonía y los otros 2 se pusieron un MecanoAmplificador.

GONIOMETRÍA | MecanoAmp | MecanoAmp Eutonía | Eutonía
Flexión de tobillo (rodilla flexión 90º) | ANTES 90/100=95º DESPUES 110º | 115/112=11 3º 110/112=11 1º 110/111=1 10º 112/113=1 12º | 110/114=1 12º 112/110=1 11º
Flexión de tobillo (rodilla extendida) | ANTES 105/105º DESPUES 105º | 102/106º=1 04º 104/102=10 3º 95/100=97 º 100/101=1 00º | 104/109=1 06º 106/104=1 05º

Extensión de rodilla
(cadera | flexión
máxima para tensar flexores rodilla) | ANTES 60/65=63º DESPUES 65º | 81/70=75º 69/70=69º

Nuestros comentarios:

En estas goniometrías no hay variaciones significativas. Estudios clínicos con personas que tienen espasticidad neuromuscular sí que han encontrado mejoría tras aplicarles vibraciones.

APORTACION
ES

Para los profesionales sanitarios interesados en participar en la investigación de la amplificación mecanoceptiva mediante el desarrollo de prototipos Mecanoamplificadores para distintos objetivos: contactadnos y daremos comienzo al proceso de diseño colaborativo

PETICIONES

REFERENCIA
S

Para las familias interesadas en probar el MecanoAmplificador para la marcha:
que nos contacte un profesional sanitario de vuestra zona (médico RHB, Fisioterapeuta).

Para los profesionales sanitarios interesados en utilizar el MecanoAmplificador para la marcha con sus pacientes:
contactadnos cuando hayáis enrolado a un Ingeniero de Telecomunicaciones/Electrónico de vuestra zona.

FEDERACIÓN INTERNACIONAL DE EUTONÍA
San Cayetano 7, 28005 (Madrid)
www.fie-eutonia.blogspot.com
A ella pertenecen:
- Instituto Internacional de Eutonía (Vigo)
- Asociación Aragonesa de Eutonía (Huesca)
- Asociación de Eutonía de Castilla-La Mancha (Alcázar de S. Juan)
- Asociación Madrileña de Eutonía (Madrid)
- Asociación Raymond Murcia (Burdeos)
En Albacete hemos practicado con Rosa Cuevas Atienza, quien nos visita mensualmente porque reside en Granada. Su contacto es rosa-cuevas@hotmail.com y su Tf móvil 617 169 606

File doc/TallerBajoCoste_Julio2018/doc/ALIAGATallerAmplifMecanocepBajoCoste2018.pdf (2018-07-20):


## AMPLIFICACIÓN MECANOCEPTIVA

M.Teresa Aliaga Vega

Fisioterapeuta especializada en biomecánica y neuromotricidad.

Consejería de Educación Castilla-LaMancha.

Albacete, Julio 2018

AMPLIFICACIÓN MECANOCEPTIVA Introducción

Percepción mecánica
Las ayudas sensoriales artificiales

Un Mecanoamplificador(CC)

M.Teresa Aliaga Vega

Del conocimiento empírico a la evidencia científica Investigación y desarrollo
Conclusiones

AMPLIFICACIÓN MECANOCEPTIVA Percepción mecánica

M.Teresa Aliaga Vega

## movimientos en el espacio/postura corporal +interacción con soportes u objetos

AMPLIFICACIÓN MECANOCEPTIVA Percepción mecánica


M.Teresa Aliaga Vega

MANCUSO_ sensibilidad e inteligencia vegetal (2015) BARTH_ecology of sensing (2001)

AMPLIFICACIÓN MECANOCEPTIVA Percepción mecánica


M.Teresa Aliaga Vega

JOSA BULLICH_mecanoceptores rodilla (1996) MORAES_hip mechanoreceptors (2011)

AMPLIFICACIÓN MECANOCEPTIVA Percepción mecánica


M.Teresa Aliaga Vega


MERZENICH _reorganización de las áreas corticales (1982) PURVES_neurociencia (2016)

AMPLIFICACIÓN MECANOCEPTIVA Las ayudas sensoriales artificiales


M.Teresa Aliaga Vega

AMPLIFICACIÓN MECANOCEPTIVA Las ayudas sensoriales artificiales


ROVELLA_ eutonía (2008)

Rosa Cuevas Atienza

AMPLIFICACIÓN MECANOCEPTIVA Las ayudas sensoriales artificiales

M.Teresa Aliaga Vega


BACH-Y-RITA_sensory substitution & human interface (2003)

AMPLIFICACIÓN MECANOCEPTIVA Un Mecanoamplificador(CC)


M.Teresa Aliaga Vega

https://github.com/leobotmanuel/MecanoAmplificador

AMPLIFICACIÓN MECANOCEPTIVA Un Mecanoamplificador(CC)

M.Teresa Aliaga Vega

AMPLIFICACIÓN MECANOCEPTIVA Un Mecanoamplificador(CC)


Susana Blanco Magadán


AMPLIFICACIÓN MECANOCEPTIVA Precauciones y aplicaciones

a=12G=118 m/seg
2
EPILEPSIA

REFLEJA

IRRITACIÓN
2

M.Teresa Aliaga Vega

E= 51 J/15 min

NORDIN_ biomecánica sistema músculoesquelético (2004) RD 1311_exposición a vibraciones mecánicas (2005)

AMPLIFICACIÓN MECANOCEPTIVA Precauciones y aplicaciones

ALTERACIONES
NEUROMOTRICES


tipo de sensor
y ubicación

M.Teresa Aliaga Vega


objetivo funcional

AMPLIFICACIÓN MECANOCEPTIVA Del conocimiento empírico a la evidencia científica

EMG, RMC, VICON, ¿?


M.Teresa Aliaga Vega


KRAUSE_ alleviation impairments in cerebral palsy (2017) BUTLER_depresión actividad involuntaria medular (2006) CAMEROTA_effects on stroke (2010)

AMPLIFICACIÓN MECANOCEPTIVA Del conocimiento empírico a la evidencia científica

M.Teresa Aliaga Vega


Test “Get up&go” + Test “10m Walk”

ALIAGA Y RECIO_fiabilidad goniometría (2007) VIEL_marcha humana (2002)

AMPLIFICACIÓN MECANOCEPTIVA Del conocimiento empírico a la evidencia científica


M.Teresa Aliaga Vega


CAÑA-PINO_valoración instrumental control postural (2018) WOLFF_postural balance in cerebral palsy (2002) WANG_postural balance in autism (2016)

PLATAFORMA DE FUERZAS

AMPLIFICACIÓN MECANOCEPTIVA Investigación y desarrollo


M.Teresa Aliaga Vega

TA PIZ RODANTE

AMPLIFICACIÓN MECANOCEPTIVA Investigación y desarrollo


M.Teresa Aliaga Vega

CLARK_wiifit validada para valorar equilibrio (2009)

BALANCE BOARD + ORDENADOR

AMPLIFICACIÓN MECANOCEPTIVA Conclusiones


M.Teresa Aliaga Vega
